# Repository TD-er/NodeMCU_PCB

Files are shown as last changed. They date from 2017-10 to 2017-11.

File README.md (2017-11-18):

# NodeMCU_PCB
PCB Design of a test print to be used with the NodeMCU v1.0 and numerous I2C components and OLED displays and a MH-Z19 CO2 sensor

Some Fritzing parts I used, I made myself. See: https://github.com/TD-er/fritzing-parts

## Inspect before production

Rev 1 of the PCB appeared to have incorrect hole diameter for the NodeMCU, so that board should not be produced by anyone.
Too bad I discovered this after production of the PCB.

For the rev. 2 of this board, I used the free Gerber PCB viewer [ZofzPCB](https://www.zofzpcb.com/)
This viewer can inspect all hole diameters and net routes.
Also the distances between holes are easy to inspect.

Too bad loading the Gerber files takes about 25 minutes on my Core i7 laptop. Therefore the Zofz project file is also included.

N.B. make sure no unnecessary small hole diameter is used. Some PCB manufacturers charge extra for small drill diameters (e.g. less than 30 mil diameter). Fritzing uses very small drill holes for a via. In this revision, I only used via's on locations where already was a drill hole for a soldering pin.
This version has no drill holes less than 30 mil diameter.

## Rev 2 PCB

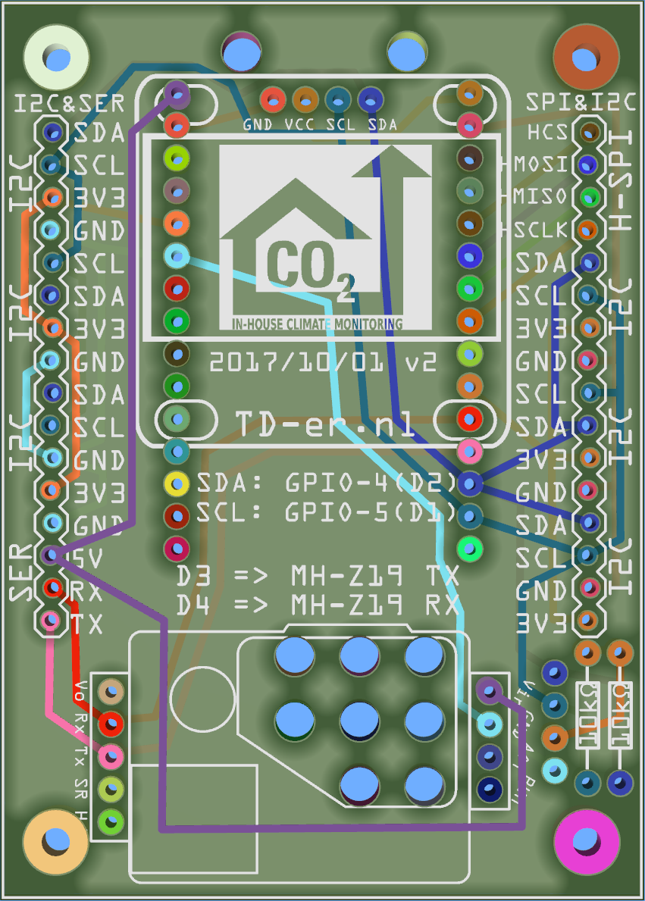
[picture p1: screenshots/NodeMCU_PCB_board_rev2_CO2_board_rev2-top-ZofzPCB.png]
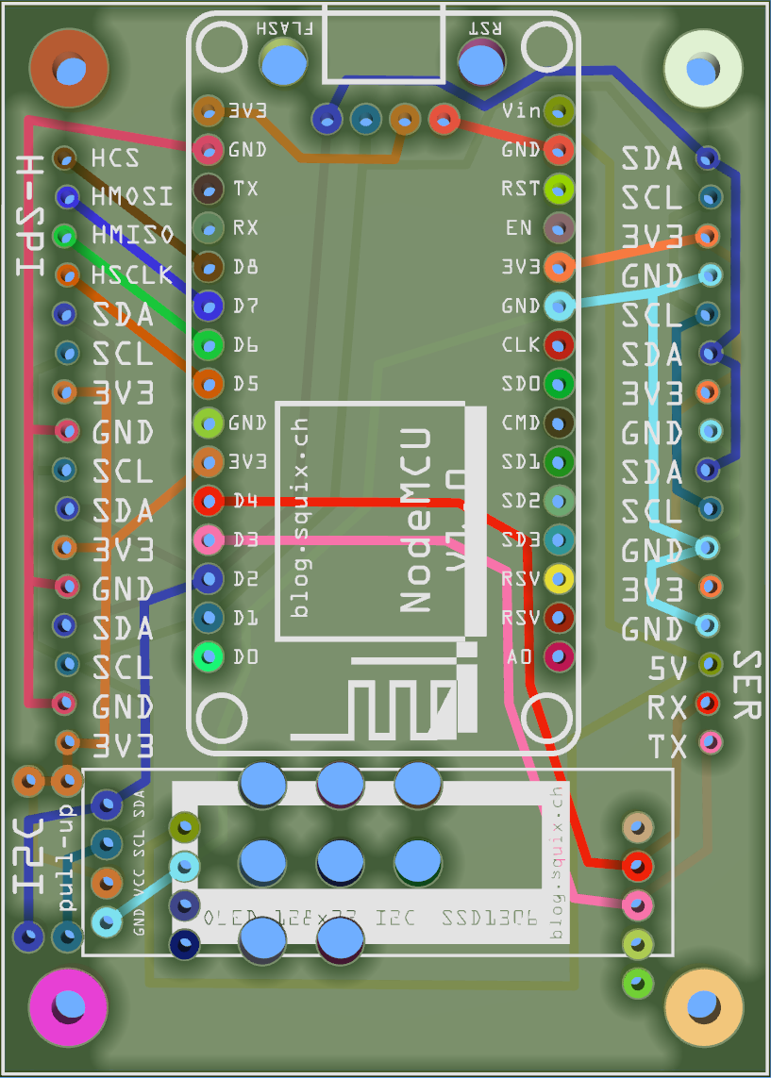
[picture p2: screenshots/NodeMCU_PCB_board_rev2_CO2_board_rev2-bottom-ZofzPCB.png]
 

The screenshots are taken from the free Gerber PCB viewer ZofzPCB.

This board has room for:
* OLED I2C display with GND, Vcc, SCL, SDA pinout 
* NodeMCU v1.0 positioned on the bottom of the PCB.
* [MH-Z19](http://www.winsen-sensor.com/products/ndir-co2-sensor/mh-z19.html) or [SenseAir S8](https://senseair.com/products/size-counts/s8-residential/) CO2 sensor.
* Numerous I2C pinout combinations for almost all sensor sold at webshops.
* Two pull-up resistors for the I2C lines.
* Easy access to pins 5V, D3 (GPIO-0) and D4 (GPIO-2), which will be used as RX/TX when CO2 sensor is connected.
* Easy access to hardware SPI pins

Used pins:
* D1 (GPIO5)  SCL
* D2 (GPIO4)  SDA
* D3 (GPIO0)  TX
* D4 (GPIO2)  RX
* D5 (GPIO14) HSCLK
* D6 (GPIO12) HMISO
* D7 (GPIO13) HMOSI
* D8 (GPIO15) HCS

### Suitable enclosure
The PCB fits exactly in the [75 x 54 x 27mm ABS plastic case](https://www.banggood.com/10pcs-DIY-Plastic-Project-Housing-Electronic-Junction-Case-Power-Supply-Box-p-1168741.html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) with the USB port of the NodeMCU in front of the hole in the case.
Even the OLED displays fit exactly when using these [pinheaders](https://www.banggood.com/10pcs-40Pin-2_54mm-Female-Header-Connector-Socket-For-DIY-Arduino-p-945516.html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).
Only a hole has to be made inside the case for the display.

### Holes and their use
There are holes in the PCB at the position of the flash and reset buttons of the NodeMCU. These can be used to ease drilling holes in the bottom of the plastic case before soldering the NodeMCU.

The holes under the CO2 sensor are needed to supply the air to the Senseair S8 CO2 sensor. When using the MH-Z19 CO2 sensor, they are not needed, but more ventilation is always a good thing when sensing air quality.

### I2C connections and pull-up resistors
The I2C pins at both sides (left/right) of the board appear random, but they can support almost any I2C sensor board available online.
Most of these boards use different order of pinout signals.
The same order is positioned on the left and on the right, to allow for sensor boards which have the sensor on the "other" side. Some sensors you may want to direct to the outside of the box (e.g. temperature sensor).

There is room for 2 resistors.
Often I2C needs additional pull-up resistors to function well. A good value for 100 kHz I2C is a 10k resistor. One for the clock line and one for the data line.

### OLED displays
There is room for a small display at the same side as the NodeMCU and a bigger one at the "top" side of the PCB.
Make sure to solder the pin-header for the bigger display first and then the NodeMCU.
Please note there are OLED displays with other pinouts. I used the GND, Vcc, SCL, SDA variant.

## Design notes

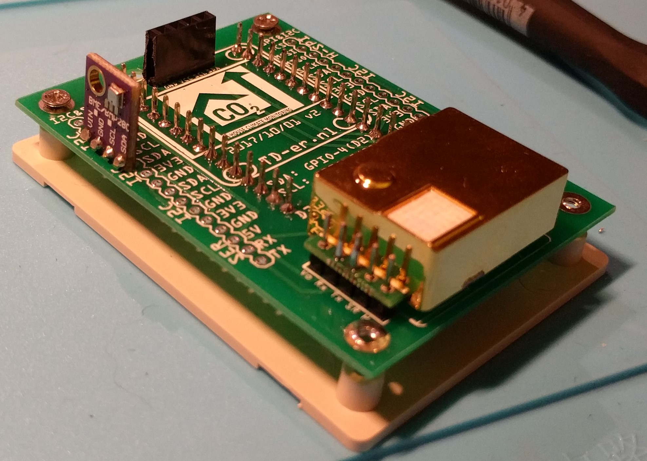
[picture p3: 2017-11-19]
photos/CO2_Sensor_board_rev2.jpg

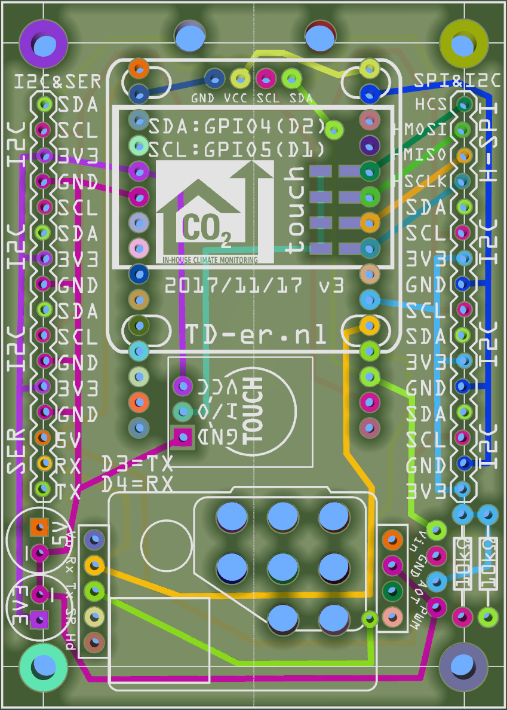
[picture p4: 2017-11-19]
screenshots/NodeMCU_PCB_board_rev2_CO2_board_rev3-top-ZofzPCB.png

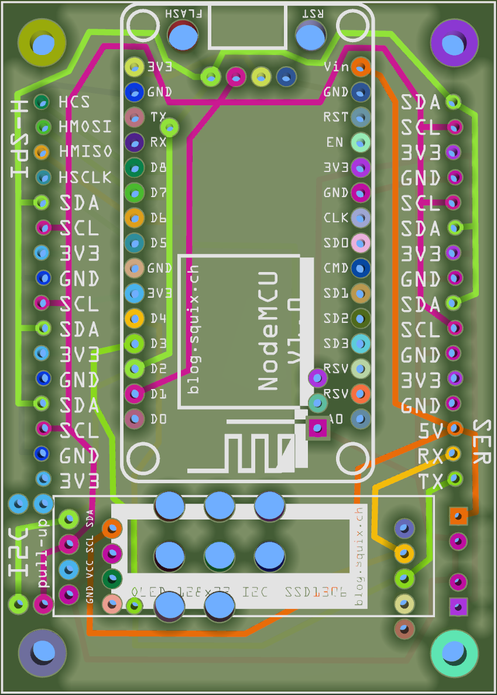
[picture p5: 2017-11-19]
screenshots/NodeMCU_PCB_board_rev2_CO2_board_rev3-bottom-ZofzPCB.png

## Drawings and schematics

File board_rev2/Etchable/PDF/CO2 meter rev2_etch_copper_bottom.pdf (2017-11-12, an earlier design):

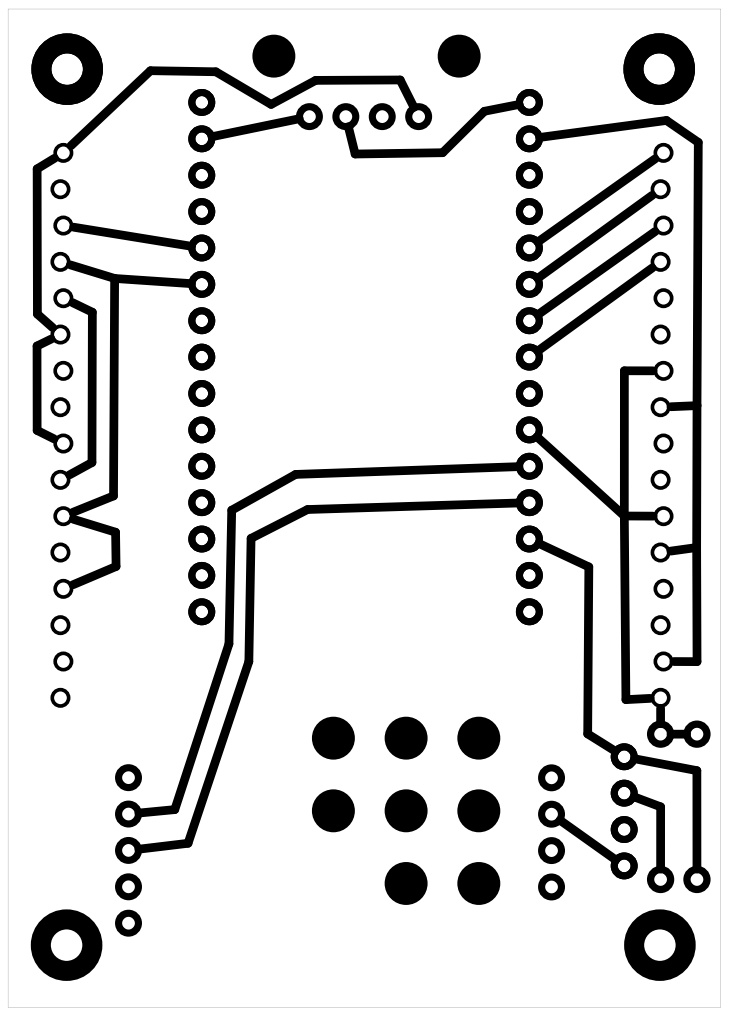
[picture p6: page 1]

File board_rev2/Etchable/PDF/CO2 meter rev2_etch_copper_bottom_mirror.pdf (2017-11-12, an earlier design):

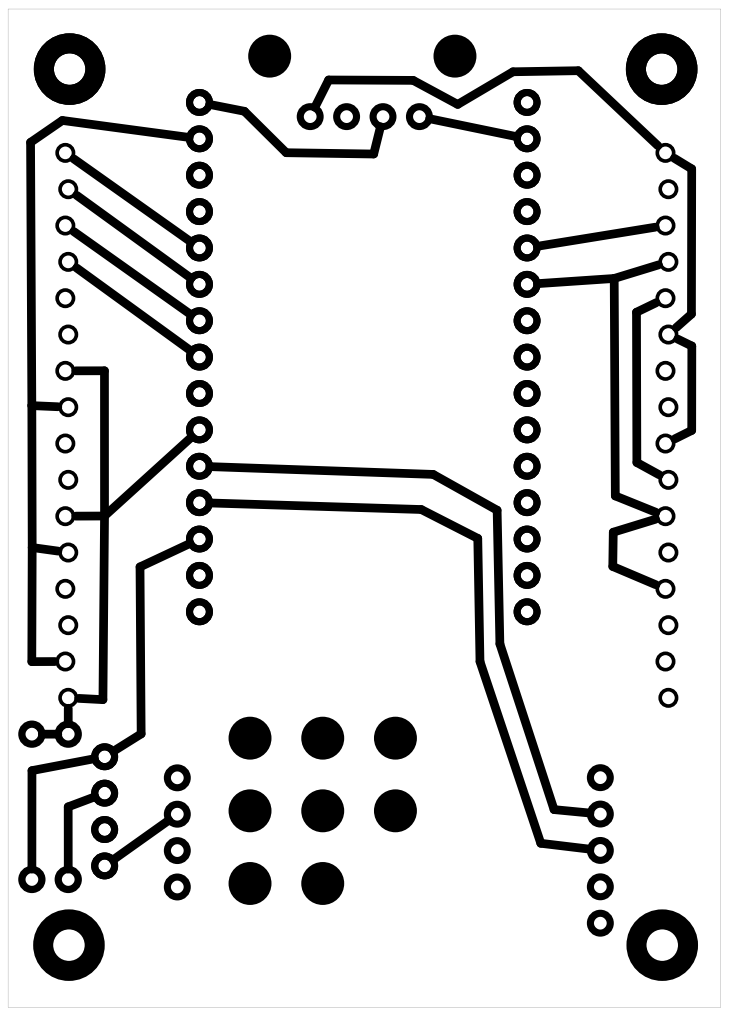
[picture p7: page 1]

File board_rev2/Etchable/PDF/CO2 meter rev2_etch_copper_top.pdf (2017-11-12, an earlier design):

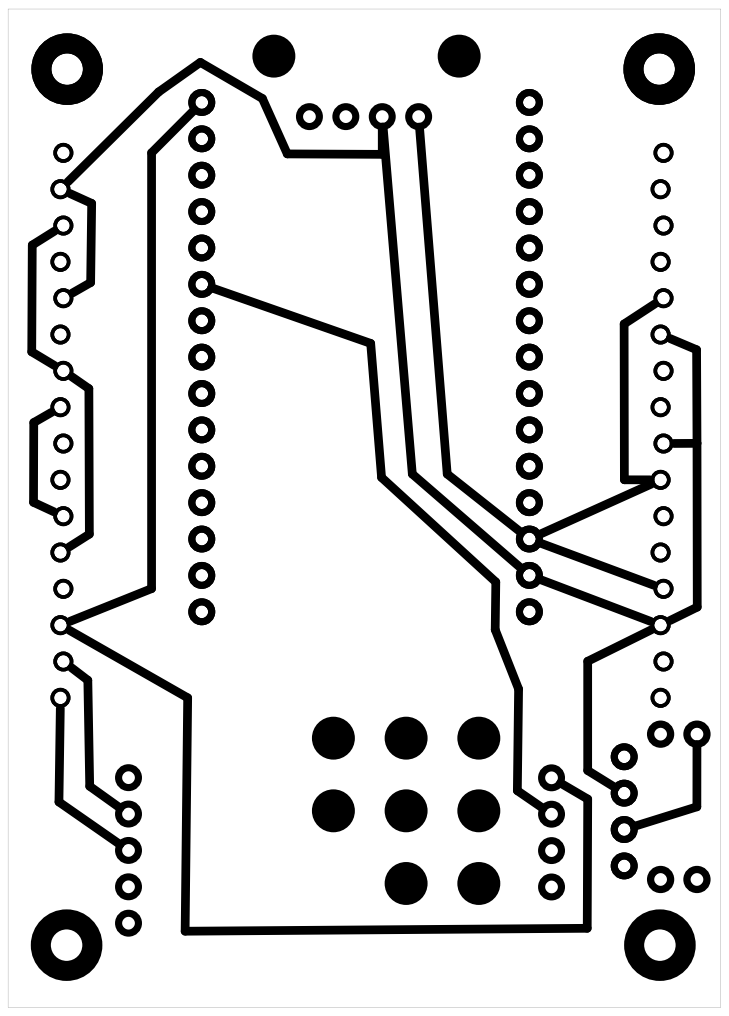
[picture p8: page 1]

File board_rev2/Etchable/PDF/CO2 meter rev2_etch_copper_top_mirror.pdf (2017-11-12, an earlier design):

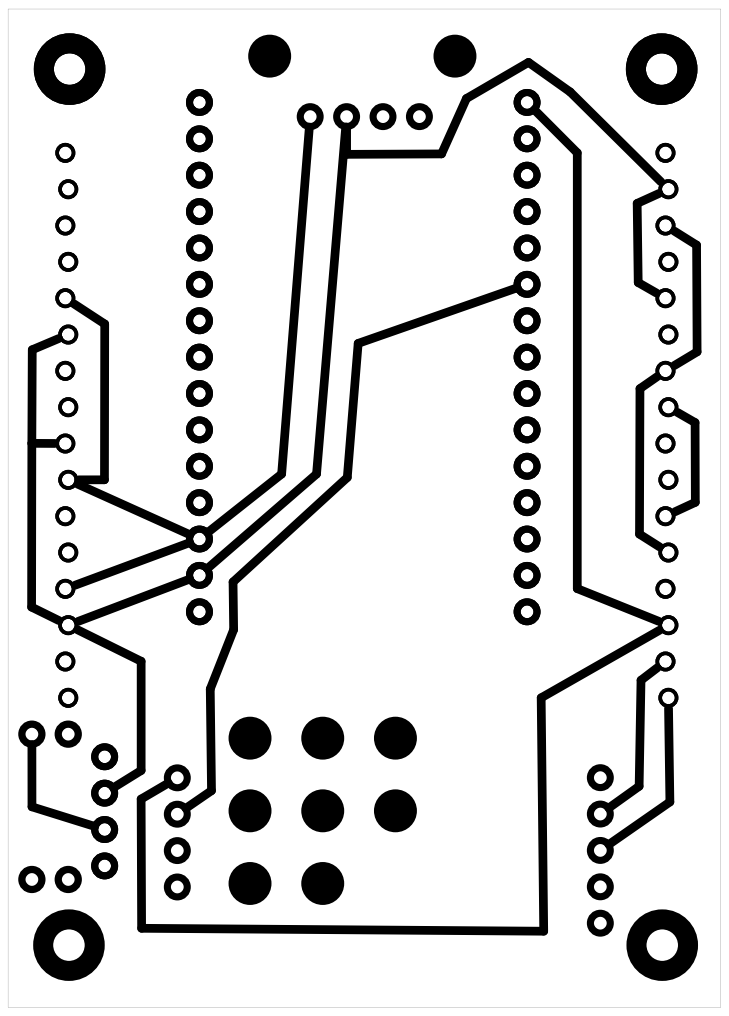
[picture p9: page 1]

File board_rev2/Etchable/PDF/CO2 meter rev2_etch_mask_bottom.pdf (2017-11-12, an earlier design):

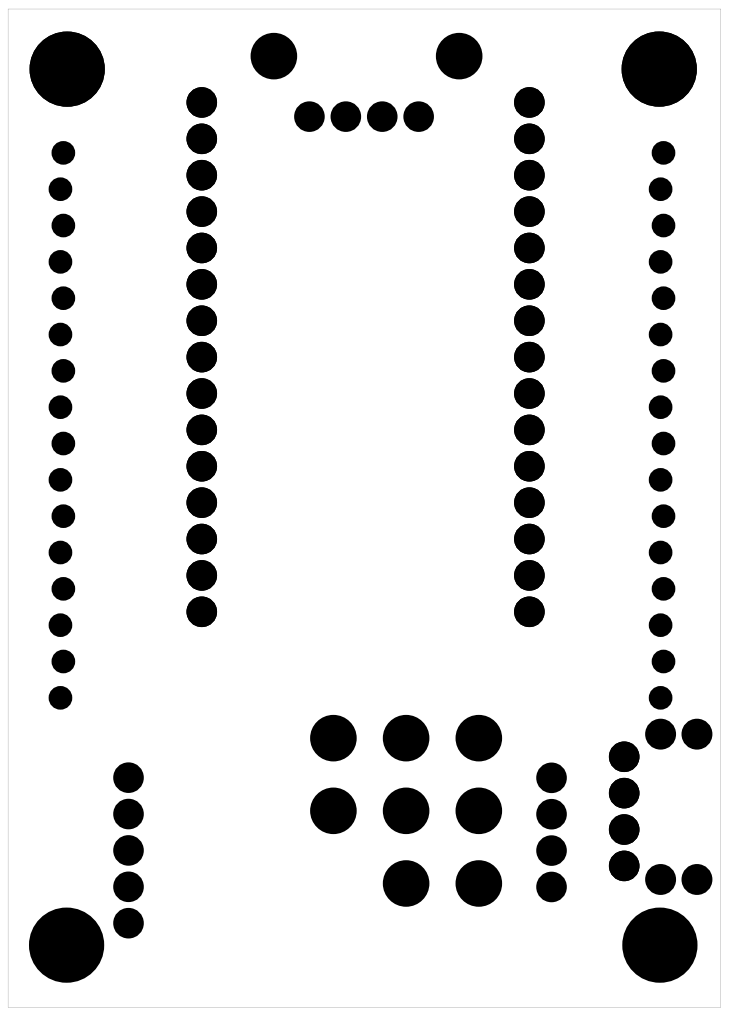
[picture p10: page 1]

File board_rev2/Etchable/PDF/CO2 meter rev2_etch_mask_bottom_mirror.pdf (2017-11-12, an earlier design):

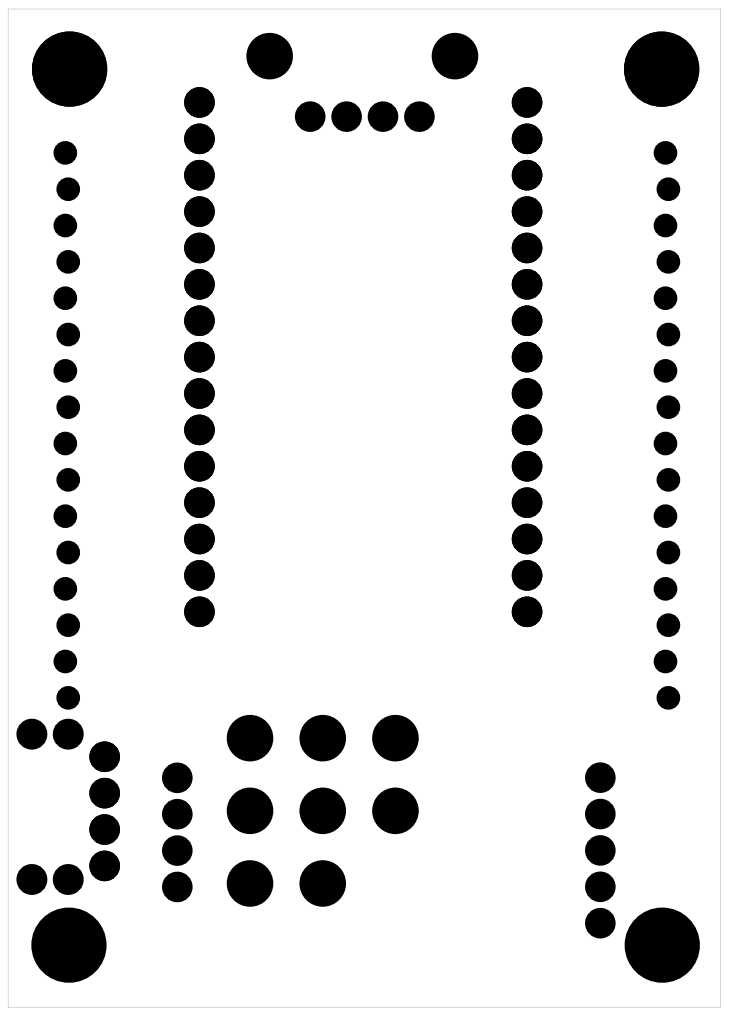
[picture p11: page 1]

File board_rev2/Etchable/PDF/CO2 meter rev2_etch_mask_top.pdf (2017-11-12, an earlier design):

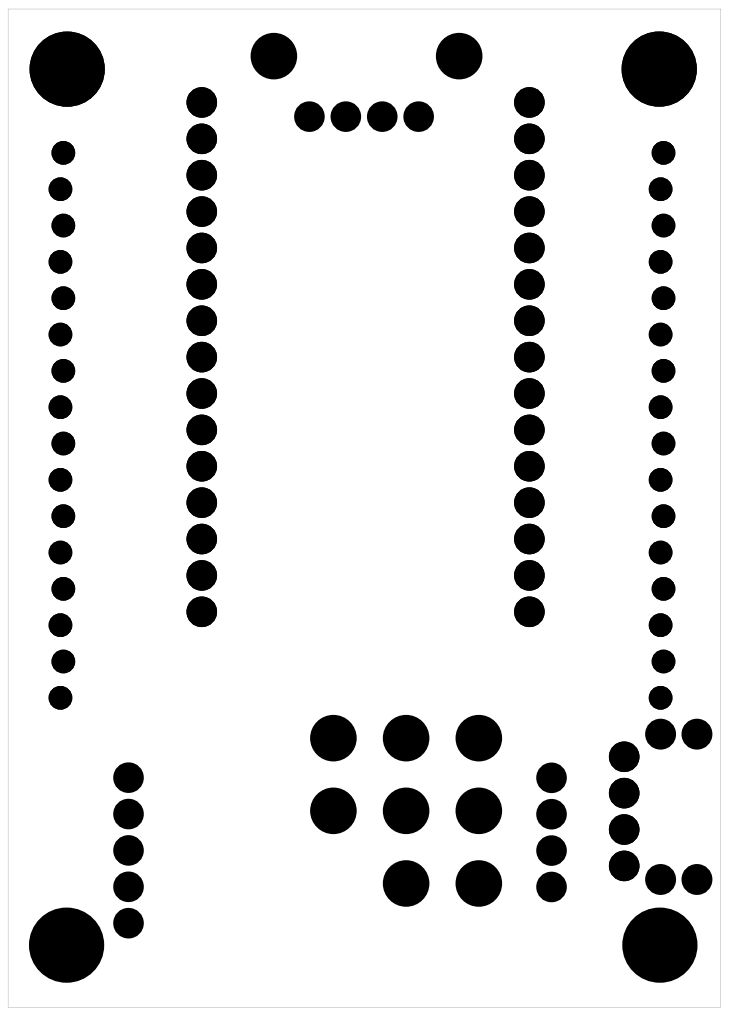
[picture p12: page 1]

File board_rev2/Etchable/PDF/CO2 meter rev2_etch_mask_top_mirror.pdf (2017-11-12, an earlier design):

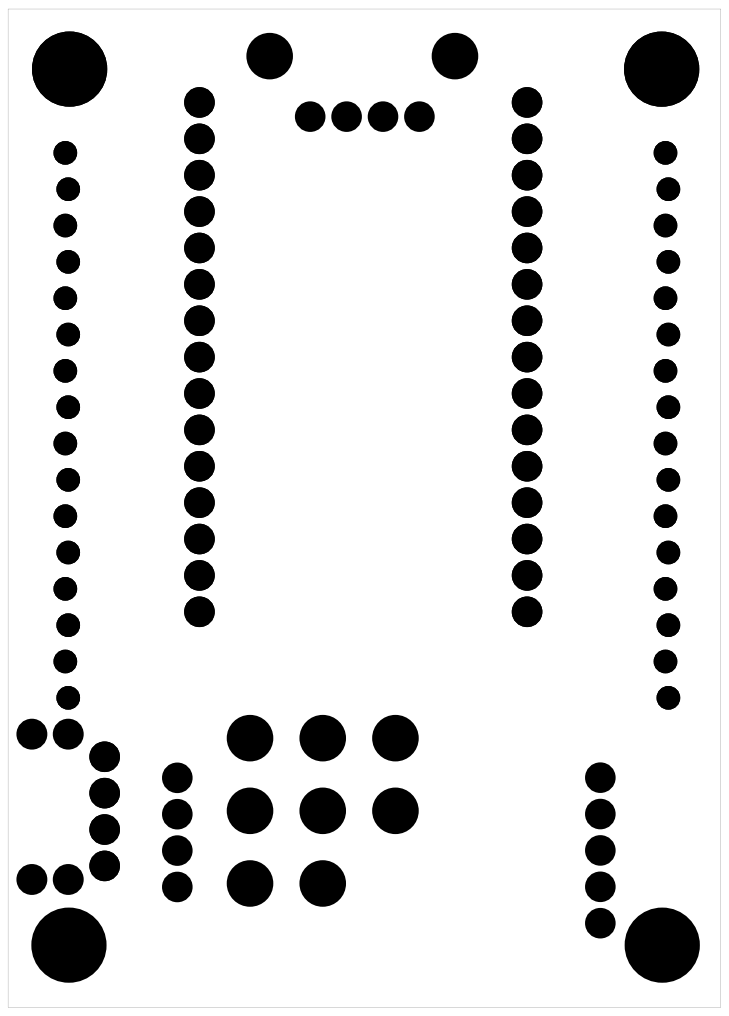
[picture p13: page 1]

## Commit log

2017-10-22 [CO2 board] Fritzing file of PCB design
    [CO2 meter rev2.fzz]
2017-10-22 [CO2 board] Gerber files and PDF Etchable exports from Fritzing
    The Gerber files and Etchable PDF's generated by Fritzing
    [CO2 meter rev2_contour.gm1, CO2 meter rev2_copperBottom.gbl, CO2 meter rev2_copperTop.gtl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]
2017-10-22 [CO2 board] ZofzPCB viewer file to inspect Gerber files
    ZofzPCB is a really nice free Gerber PCB inspect tool. See https://www.zofzpcb.com/
    However loading the files for the first time takes about 25 minutes on my i7 laptop. Therefore saving the project file makes sense.
2017-10-22 [CO2 board-rev 2] Screenshots taken from ZofzPCB viewer
2017-10-22 Description of rev 2 board
2017-10-28 [CO2 board-rev2] Rerouted 5V line to remove via and stay away from WiFi
    I noticed I had still one drill hole with a diameter less than 30 mil.
    Some PCB manufacturers charge extra for such small holes and since it is not absolutely needed, I removed the via.
    Also rerouted that 5V line for the CO2 sensor to make sure no copper is near the WiFi antenna of the NodeMCU.
    [CO2 meter rev2.fzz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]
2017-10-29 About via drill holes
2017-11-12 [CO2 board-rev2] Moved NodeMCU to the edge
    Otherwise some USB cables will not fit when using the PCB inside an enclosure.
    [CO2 meter rev2.fzz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]
2017-11-17 [CO2 board-rev3] Add Touch sensor and capacitor
    The CO2 sensor may take quite some peak current, so adding a capacitor is a good idea to lessen the load and allow for some cheaper USB cables.
    Also added a Capacitive touch sensor to operate the display.
    [CO2 meter rev3.fzz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]
2017-11-18 [CO2 board-rev3] Change of routing around antenna and Touch Sensor
    Touch Sensor did not have a drill hole for the GND and connecting to GPIO16 is not a good idea, since that one does not have an interrupt.
    [CO2 meter rev3.fzz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]
2017-11-18 [CO2 board-rev3] Clean up schematic view
    A little cleaning of the schematic view.
    [CO2 meter rev3.fzz]
2017-11-19 [Enclosure] Bottom plate holes
    Drawing to help position the mounting holes of the bottom plate of the used enclosure.
2017-11-19 [Enclosure] Bottom plate holes
    Also added some guidelines to position the NodeMCU
    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
2017-11-19 [CO2 board-rev3] Correction of drill holes to mount in plastic case
    [CO2 meter rev3.fzz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]
2017-11-19 [CO2 board-rev3] Add pin selection to Touch Sensor
    Behind the front OLED display there now is a set of pads to select what GPIO could be used for the touch sensor.
    This required a redesign of the traces on the front and the back of the PCB.
    Now in general the 3.3v and GND lines are on the front and the I2C lines are on the back.
    [CO2 meter rev3.fzz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]
2017-11-19 [CO2 board-rev2] Photo of a real assembled version
    Rev2 board soldered and ready for use with a MH-Z19 CO2 sensor and a BME280 I2C sensor
